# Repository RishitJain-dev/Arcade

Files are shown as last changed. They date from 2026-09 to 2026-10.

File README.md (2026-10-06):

# Arcade
A custom console similar to the Nintendo Game&amp;Watch, with a large colorful screen, d-pad and A and B button. It also includes a USB-C connector and SD card slot. 






Using SK8612-MINI-E LEDs to provide as a visual indicator of when a button is pressed


It uses a ESP32 chip to power it and recieves power directly from a LiPo battery.

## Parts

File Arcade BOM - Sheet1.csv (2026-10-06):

Item Name | Qty | Price (total) (GBP) | Item link | Notes
ESP32-WROVER-E-N16R8 | 1 | $6.32 | https://www.digikey.co.uk/en/products/detail/espressif-systems/ESP32-WROVER-E-N16R8/11613135
Adafruit ST7789 LCD 1.9" Display | 1 | $17.50 | https://www.digikey.co.uk/en/products/detail/adafruit-industries-llc/5394/21283798?gclsrc=aw.ds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
TS02-66-60-BK-260-LCR-D | 10 | $0.11 | https://www.digikey.co.uk/short/d33hn1qf
B2B-PH-K-S | 1 | $0.12 | https://www.digikey.co.uk/en/products/detail/jst-sales-america-inc/B2B-PH-K-S/926611?gclsrc=aw.ds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
150060GS75000 | 2 (RED & GREEN) | $0.15 | https://www.digikey.co.uk/en/products/detail/w-rth-elektronik/150060GS75000/4489898?gclsrc=aw.ds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
AT-1224-TWT-5V-2-R | 1 | $0.73 | https://www.digikey.co.uk/en/products/detail/pui-audio-inc/AT-1224-TWT-5V-2-R/5011404
USB4215-03-A | 1 | $0.53 | https://www.digikey.co.uk/short/r2f9ddnd
C0603C104K5RACTU | 3 | $0.13 | https://www.digikey.co.uk/short/3578qzzw
CRCW06031K00FKEA | 6 (100, 10k, 220, 5.1k, 1k, 12k) | $0.10 | https://www.digikey.co.uk/short/nj77q28q
TPB4056B2X-ES1R | 1 | $0.52 | https://www.digikey.co.uk/en/products/detail/3peak/TPB4056B2X-ES1R/22228451?gclsrc=aw.ds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
USBLC6-2SC6 | 1 | $0.91 | https://www.digikey.co.uk/en/products/detail/umw/USBLC6-2SC6/16705896?gclsrc=aw.ds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
CH340N | 1 | $0.38 | https://www.alibaba.com/product-detail/CH340N-Package-SOP-8-Built-in_1601642738717.html?mark=google_shopping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 | min order quantity is 2
SK6812MINI-E | 8 | $1.45 | https://www.aliexpress.com/item/1005008308801366.html?src=google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
1N4148WS | 8 | $0.18 | https://www.digikey.co.uk/en/products/detail/onsemi/1N4148WS/1873805?gclsrc=aw.ds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
2000mAh LiPo battery | 1 | $10.00 | https://thepihut.com/products/2000mah-3-7v-lipo-battery
PCB | 5 | $22.90 | NA | min order quantity is 5 from jlcn (price includes shipping and assembly for SMD parts)
Total Price (GBP): |  | $62.03
Total Price (USD): |  | approx. $100
+- $10 price changes

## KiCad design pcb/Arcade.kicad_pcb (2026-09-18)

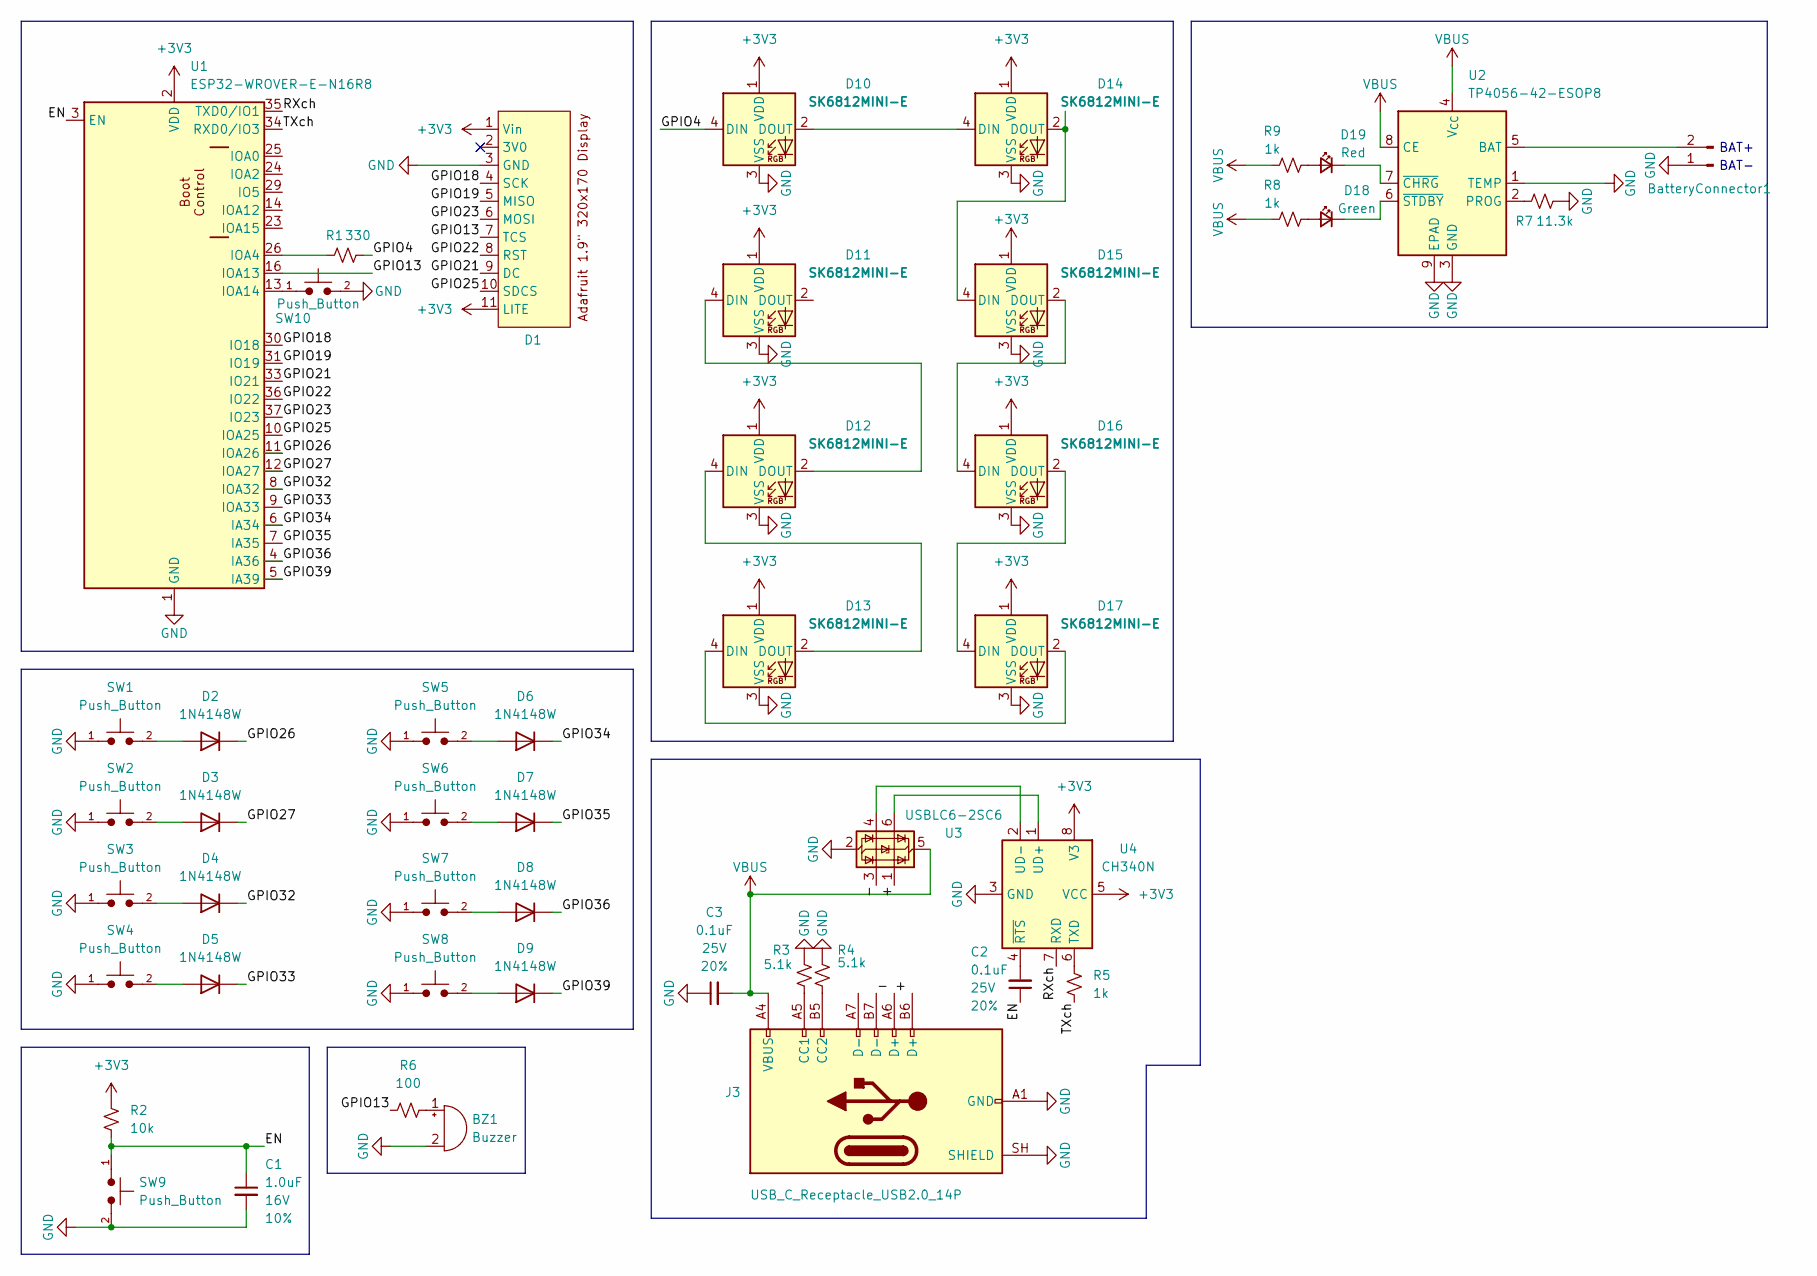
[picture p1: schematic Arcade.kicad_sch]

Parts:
BZ1: Buzzer; Buzzer_12x9.5RM7.6
BatteryConnector1: BAT-; JST_EH_B2B-EH-A_1x02_P2.50mm_Vertical
C1: 1.0uF; C_0603_1608Metric; Voltage 16V; Tolerance 10%
C2, C3: 0.1uF; C_0603_1608Metric; Voltage 25V; Tolerance 20%
D1: Adafruit 1.9 320x170 Colour IPS TFT Display (ST7789)
D2, D3, D4, D5, D6, D7, D8, D9: 1N4148W; D_SOD-123
D10, D11, D12, D13, D14, D15, D16, D17: SK6812MINI-E; LED_SK6812MINI-E_3.2x2.8mm_P1.5mm_ReverseMount
D18: Green; LED_0603_1608Metric_Green
D19: Red; LED_0603_1608Metric_Red
J3: USB_C_Receptacle_USB2.0_14P; USB_C_Receptacle_HRO_TYPE-C-31-M-12
R1: 330; R_0603_1608Metric
R2: 10k; R_0603_1608Metric
R3, R4: 5.1k; R_0603_1608Metric
R5, R8, R9: 1k; R_0603_1608Metric
R6: 100; R_0603_1608Metric
R7: 11.3k; R_0603_1608Metric
SW1, SW2, SW3, SW4, SW5, SW6, SW7, SW8, SW9, SW10: Push_Button; SW_PUSH_6mm
U1: ESP32-WROVER-E-N16R8; ESP32-WROVER-E-IE
U2: TP4056-42-ESOP8; SOIC-8-1EP_3.9x4.9mm_P1.27mm_EP2.41x3.3mm_ThermalVias
U3: USBLC6-2SC6; SOT-23-6
U4: CH340N; JEITA_SOIC-8_3.9x4.9mm_P1.27mm

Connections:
+3V3: D1.1 (Vin), D1.11 (LITE), D10.1 (VDD), D11.1 (VDD), D12.1 (VDD), D13.1 (VDD), D14.1 (VDD), D15.1 (VDD), D16.1 (VDD), D17.1 (VDD), R2.2, U1.2 (VDD), U4.5 (VCC), U4.8 (V3)
/+: J3.A6 (D+), U3.1 (I/O1)
/-: J3.B7 (D-), U3.3 (I/O2)
/EN: C1.1, C2.1, R2.1, SW9.1, U1.3 (EN)
/GPIO4: D10.4 (DIN), R1.2
/GPIO13: D1.7 (TCS), R6.1, U1.16 (IOA13)
/GPIO18: D1.4 (SCK), U1.30 (IO18)
/GPIO19: D1.5 (MISO), U1.31 (IO19)
/GPIO21: D1.9 (DC), U1.33 (IO21)
/GPIO22: D1.8 (RST), U1.36 (IO22)
/GPIO23: D1.6 (MOSI), U1.37 (IO23)
/GPIO25: D1.10 (SDCS), U1.10 (IOA25)
/GPIO26: D2.1 (K), U1.11 (IOA26)
/GPIO27: D3.1 (K), U1.12 (IOA27)
/GPIO32: D4.1 (K), U1.8 (IOA32)
/GPIO33: D5.1 (K), U1.9 (IOA33)
/GPIO34: D6.1 (K), U1.6 (IA34)
/GPIO35: D7.1 (K), U1.7 (IA35)
/GPIO36: D8.1 (K), U1.4 (IA36)
/GPIO39: D9.1 (K), U1.5 (IA39)
/RXch: U1.35 (TXD0/IO1), U4.7 (RXD)
/TXch: R5.1, U1.34 (RXD0/IO3)
GND: BZ1.2 (-), BatteryConnector1.1, C1.2, C3.1, D1.3 (GND), D10.3 (VSS), D11.3 (VSS), D12.3 (VSS), D13.3 (VSS), D14.3 (VSS), D15.3 (VSS), D16.3 (VSS), D17.3 (VSS), J3.A1 (GND), J3.A12 (GND), J3.B1 (GND), J3.B12 (GND), J3.SH (SHIELD), R3.2, R4.2, R7.2, SW1.1, SW2.1, SW3.1, SW4.1, SW5.1, SW6.1, SW7.1, SW8.1, SW9.2, SW10.2, U1.1 (GND), U1.15 (GND), U1.38 (GND), U1.39.1 (GND), U1.39.2 (GND), U1.39.3 (GND), U1.39.4 (GND), U1.39.5 (GND), U1.39.6 (GND), U1.39.7 (GND), U1.39.8 (GND), U1.39.9 (GND), U2.1 (TEMP), U2.3 (GND), U2.9 (EPAD), U3.2 (GND), U4.3 (GND)
unnamed: BZ1.1 (+), R6.2
unnamed: BatteryConnector1.2, U2.5 (BAT)
unnamed: D2.2 (A), SW1.2
unnamed: D3.2 (A), SW2.2
unnamed: D4.2 (A), SW3.2
unnamed: D5.2 (A), SW4.2
unnamed: D6.2 (A), SW5.2
unnamed: D7.2 (A), SW6.2
unnamed: D8.2 (A), SW7.2
unnamed: D9.2 (A), SW8.2
unnamed: D10.2 (DOUT), D14.4 (DIN)
unnamed: D11.4 (DIN), D12.2 (DOUT)
unnamed: D12.4 (DIN), D13.2 (DOUT)
unnamed: D13.4 (DIN), D17.2 (DOUT)
unnamed: D14.2 (DOUT), D15.4 (DIN)
unnamed: D15.2 (DOUT), D16.4 (DIN)
unnamed: D16.2 (DOUT), D17.4 (DIN)
unnamed: D18.2 (A), R8.2
unnamed: D18.1 (K), U2.6 (~STDBY)
unnamed: D19.2 (A), R9.2
unnamed: D19.1 (K), U2.7 (~CHRG)
unnamed: J3.A5 (CC1), R3.1
unnamed: J3.B5 (CC2), R4.1
unnamed: R1.1, U1.26 (IOA4)
unnamed: SW10.1, U1.13 (IOA14)
unnamed: R7.1, U2.2 (PROG)
unnamed: R5.2, U4.6 (TXD)
unnamed: U3.6 (I/O1), U4.1 (UD+)
unnamed: U3.4 (I/O2), U4.2 (UD-)
unnamed: C2.2, U4.4 (~RTS)
VBUS: C3.2, J3.A4 (VBUS), J3.A9 (VBUS), J3.B4 (VBUS), J3.B9 (VBUS), R8.1, R9.1, U2.4 (V_{CC}), U2.8 (CE), U3.5 (VBUS)

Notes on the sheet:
BAT+
BAT-

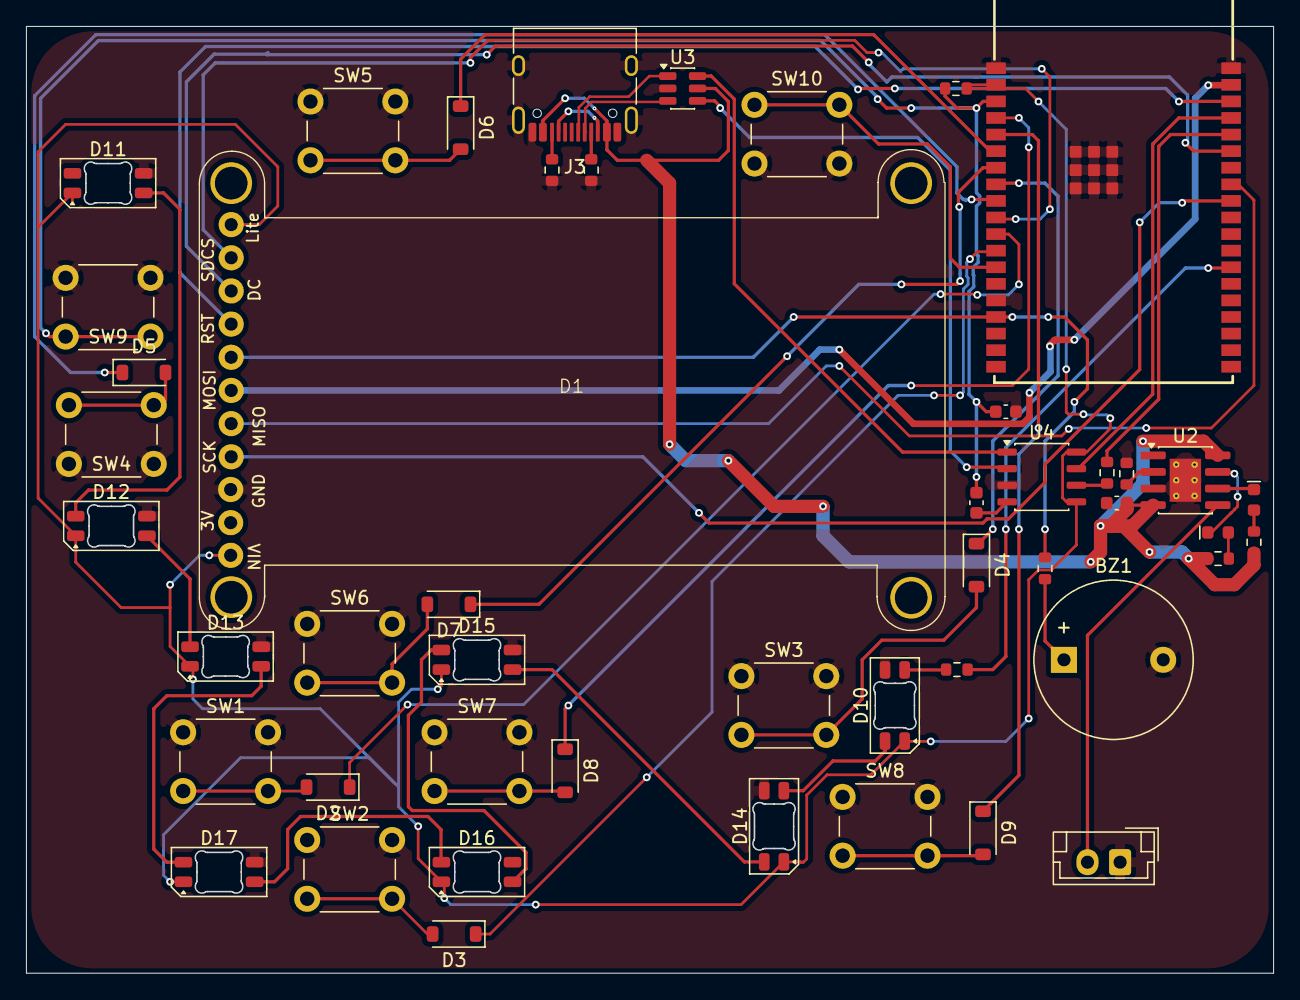
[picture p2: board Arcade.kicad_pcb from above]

Board: 2 copper layers, 95.5 x 72.5 mm, 48 parts (0 on the bottom side), 54 nets.

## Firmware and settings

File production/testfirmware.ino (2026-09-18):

#include <Arduino.h>
#include <Adafruit_GFX.h>
#include <Adafruit_ST7789.h>
#include <SPI.h>

#define TFT_CS    5
#define TFT_DC    16
#define TFT_RST   17

#define BTN_UP    12
#define BTN_DOWN  13
#define BTN_LEFT  14
#define BTN_RIGHT 27
#define BTN_A     25
#define BTN_B     26

Adafruit_ST7789 tft = Adafruit_ST7789(TFT_CS, TFT_DC, TFT_RST);

const int buttons[] = {BTN_UP, BTN_DOWN, BTN_LEFT, BTN_RIGHT, BTN_A, BTN_B};
const char* btnNames[] = {"UP", "DOWN", "LEFT", "RIGHT", "A", "B"};
int lastState[] = {HIGH, HIGH, HIGH, HIGH, HIGH, HIGH};

void setup() {
  Serial.begin(115200);

  for (int i = 0; i < 6; i++) {
    pinMode(buttons[i], INPUT_PULLUP);
  }

  tft.init(170, 320);
  tft.setRotation(1);
  tft.fillScreen(ST77XX_BLACK);
  
  tft.setTextColor(ST77XX_WHITE);
  tft.setTextSize(2);
  tft.setCursor(20, 20);
  tft.println("ESP32 Handheld Test");

  tft.setTextSize(1);
  tft.setCursor(20, 60);
  tft.println("Press any button...");
}

void loop() {
  for (int i = 0; i < 6; i++) {
    int state = digitalRead(buttons[i]);
    
    if (state != lastState[i]) {
      if (state == LOW) {
        tft.fillRect(20, 100, 200, 30, ST77XX_BLACK);
        tft.setTextSize(2);
        tft.setTextColor(ST77XX_GREEN);
        tft.setCursor(20, 100);
        tft.print("Pressed: ");
        tft.print(btnNames[i]);

        Serial.print("Button pressed: ");
        Serial.println(btnNames[i]);
      }
      lastState[i] = state;
      delay(20);
    }
  }
}

##lowk had to google smn every line
##if it doesnt work ill just change it as i go

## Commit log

2026-09-18 Expand README with design process and BOM details
    Added detailed sections on schematic and PCB design, including images and links to timelapse videos. Organized GitHub repository and created a Bill of Materials (BOM).
2026-09-18 re organised the repo
    [Arcade.kicad_pcb, Arcade.kicad_sch]
2026-10-06 Update README to simplify design process details
    Removed detailed design steps and images for schematic, PCB, and GitHub organization.
2026-10-06 Update README with LED indicator information
    Added a new image and description about SK8612-MINI-E LEDs.
2026-10-06 Modify prices and total in Arcade BOM
    Updated item prices and added total price in USD.
    [Arcade BOM - Sheet1.csv]
2026-10-06 Revise Arcade BOM with updated prices and items
    Updated item list with new prices and quantities.
    [Arcade BOM - Sheet1.csv]
2026-10-06 Update Arcade BOM with new items and prices
    [Arcade BOM - Sheet1.csv]
2026-10-06 Update Arcade BOM with new item prices and links
    [Arcade BOM - Sheet1.csv]
